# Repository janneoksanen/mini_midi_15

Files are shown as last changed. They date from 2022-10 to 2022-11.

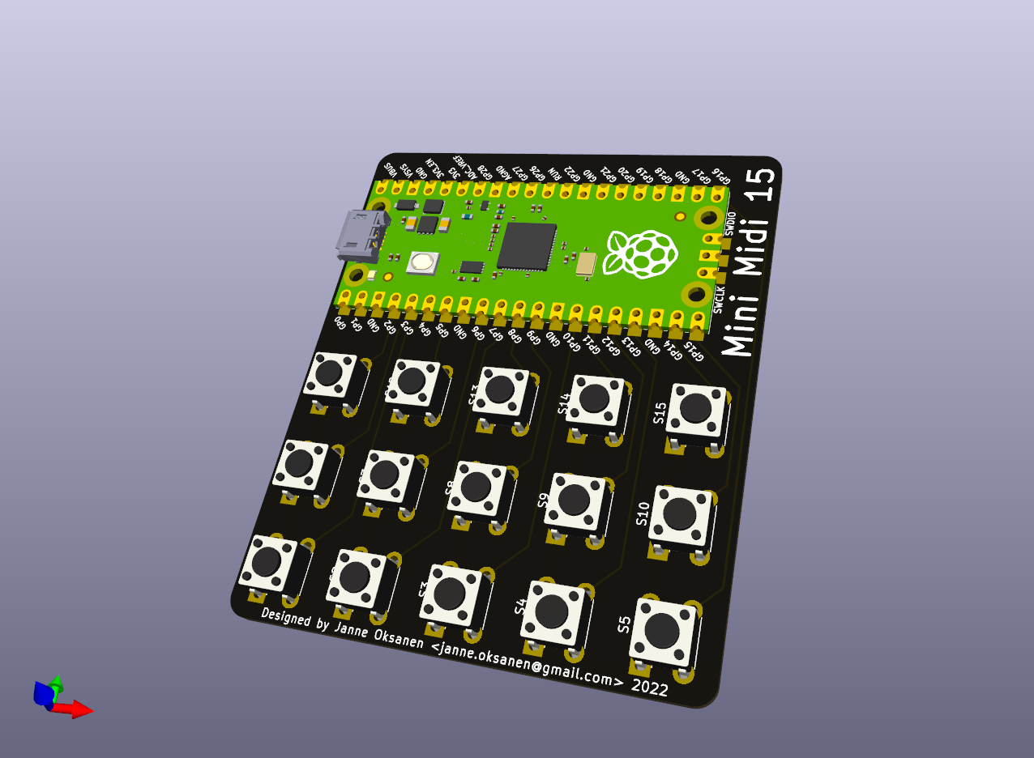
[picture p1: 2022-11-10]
15_button_controller.png

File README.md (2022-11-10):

This is a 15 button USB midi controller based on Raspberry Pi Pico. I created this project because I wanted to be able to control my NeuralDSP guitar amp simulation software. 

The hardware design is based around Raspberry Pi Pico and 6mm tactile switches. The cost to manufacture the PCB should be less than 10 USD for a batch of 5 with shipping included. Raspberry Pi Pico is about 4 USD and the switches liteally cost about a cent each. The total cost of one controller should therefore be about 6 USD and change (micro USB cable not included). 

PCB design was done using KiCad 6
https://www.kicad.org/

The software is based on CircuitPython and uses the Adafruit MIDI library.

Adafruit CircuitPython is released under MIT licence. See the details here:
https://docs.circuitpython.org/en/latest/docs/LICENSE.html?

For installation instructions see the README.txt file inside the firmware directory.

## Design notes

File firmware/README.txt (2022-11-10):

Files included:

adafruit-circuitpython-raspberry_pi_pico-en_US-7.3.3.uf2

	A slightly modified version of Adafruit Circuitpython.
	Only difference is the name of the USB midi device.
	
adafuit_midi

	Adafruid midi library. Added here for convenience so
	that you don't have to download the whole library pack.

Adafuit CircuitPython is published under the MIT licence.
Read licence details here: 
https://docs.circuitpython.org/en/latest/docs/LICENSE.html

code.py

	The actual program that runs the board. By default MIDI
	channel is set to 1. Buttons S1 through S5 send program
	change messages 1 through 5. Buttons 6 through 15 send
	control change messages 1 through 10 with corresponding
	values 1 through 10. If you know any amount of programming
	you should have no problems customizing the code to suit
	your needs.
	
	Check out the MIDI library documentation here:
	https://docs.circuitpython.org/projects/midi/en/latest/api.html#

Installation instructions:

	1. Plug the board into USB
	2. Copy adafruit-circuitpython-raspberry_pi_pico-en_US-7.3.3.uf2
		to the root of the USB drive that appears. The USB drive will
		go away briefly while the Pico installs CircuitPython. It
		will then reappear with a directory called lib in the root
	3. Copy adafuit_midi directory with all its contents inside lib
	4. Replace the code.py file in the root of the USB drive with 
		the code.py provided by me.
	Your MiniMidi 15 is now ready to rock (or pop I don't judge)

Happy hacking, 
Janne Oksanen

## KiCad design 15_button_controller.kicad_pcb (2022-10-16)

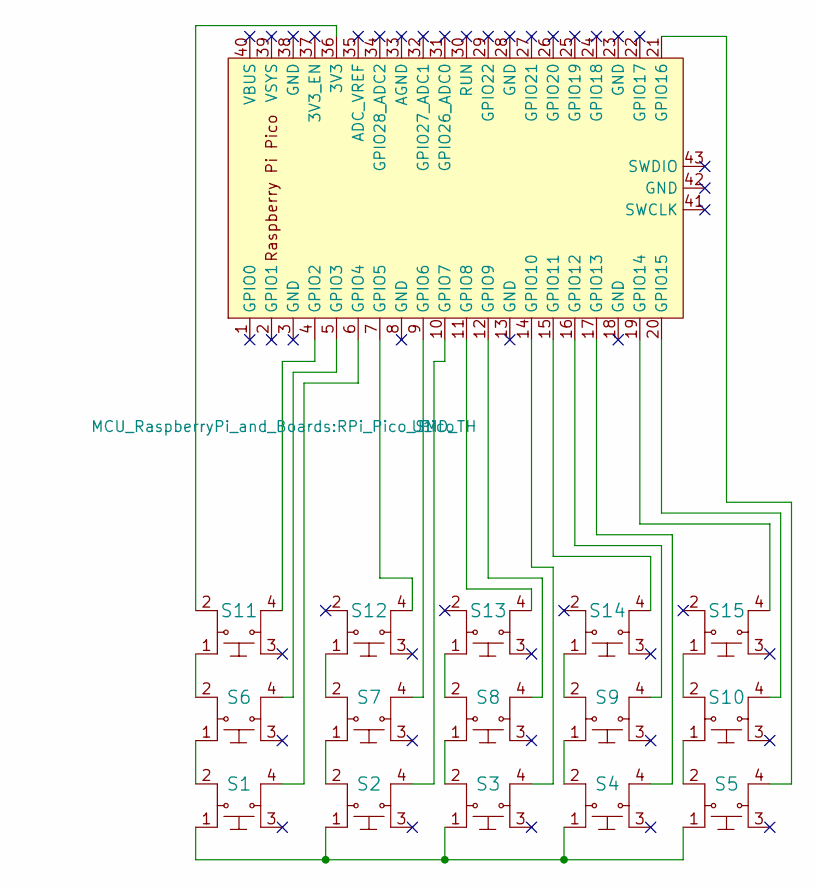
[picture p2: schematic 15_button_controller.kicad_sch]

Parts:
S1, S2, S3, S4, S5, S6, S7, S8, S9, S10, S11, S12, S13, S14, S15: 1825910-6; Switch_Tactile_THT_6x6mm; MPN 1825910-6; Digi-Key_PN 450-1650-ND
U1: Pico; RPi_Pico_SMD_TH

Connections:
unnamed: S1.1, S2.1, S3.1, S4.1, S5.1
unnamed: S1.2, S6.1
unnamed: S1.4, U1.6 (GPIO4)
unnamed: S2.2, S7.1
unnamed: S2.4, U1.10 (GPIO7)
unnamed: S3.2, S8.1
unnamed: S3.4, U1.14 (GPIO10)
unnamed: S4.2, S9.1
unnamed: S4.4, U1.17 (GPIO13)
unnamed: S5.4, U1.21 (GPIO16)
unnamed: S6.4, U1.5 (GPIO3)
unnamed: S7.4, U1.9 (GPIO6)
unnamed: S8.4, U1.12 (GPIO9)
unnamed: S9.4, U1.16 (GPIO12)
unnamed: S5.2, S10.1
unnamed: S10.2, S15.1
unnamed: S10.4, U1.20 (GPIO15)
unnamed: S6.2, S11.1
unnamed: S11.2, U1.36 (3V3)
unnamed: S11.4, U1.4 (GPIO2)
unnamed: S7.2, S12.1
unnamed: S12.4, U1.7 (GPIO5)
unnamed: S8.2, S13.1
unnamed: S13.4, U1.11 (GPIO8)
unnamed: S9.2, S14.1
unnamed: S14.4, U1.15 (GPIO11)
unnamed: S15.4, U1.19 (GPIO14)

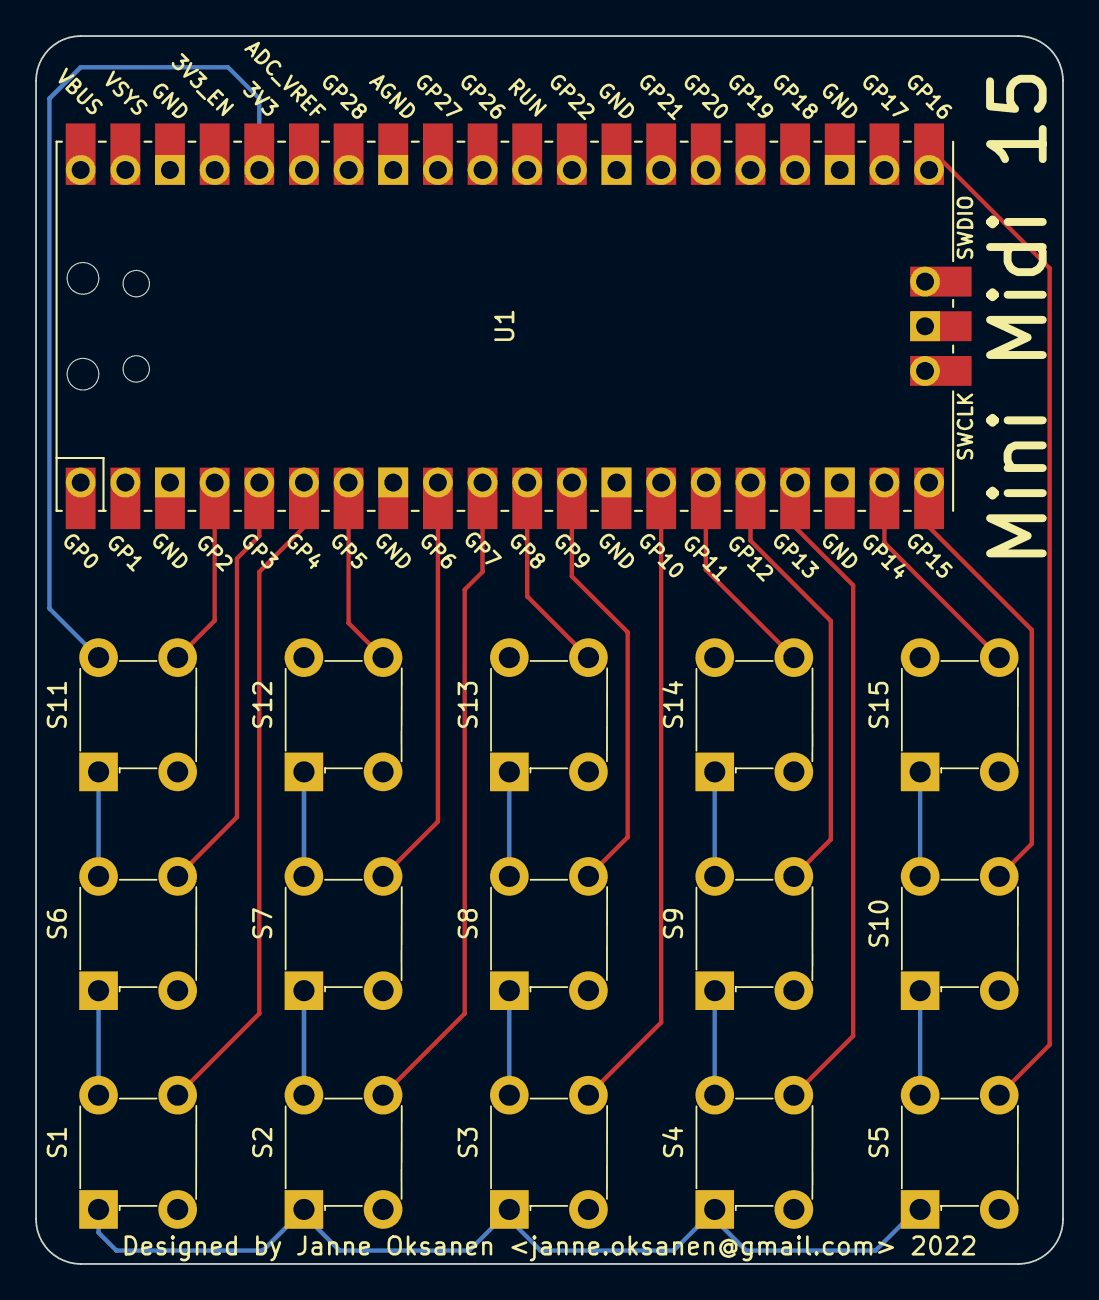
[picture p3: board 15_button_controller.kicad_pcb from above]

Board: 2 copper layers, 58.4 x 69.8 mm, 16 parts (0 on the bottom side), 27 nets.

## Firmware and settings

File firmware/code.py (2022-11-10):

import time
import board
from digitalio import DigitalInOut, Direction, Pull
import usb_midi
import adafruit_midi

led = DigitalInOut(board.LED)
led.direction = Direction.OUTPUT

s1 = DigitalInOut(board.GP4)
s1.direction = Direction.INPUT
s1.pull = Pull.DOWN

s2 = DigitalInOut(board.GP7)
s2.direction = Direction.INPUT
s2.pull = Pull.DOWN

s3 = DigitalInOut(board.GP10)
s3.direction = Direction.INPUT
s3.pull = Pull.DOWN

s4 = DigitalInOut(board.GP13)
s4.direction = Direction.INPUT
s4.pull = Pull.DOWN

s5 = DigitalInOut(board.GP16)
s5.direction = Direction.INPUT
s5.pull = Pull.DOWN

s6 = DigitalInOut(board.GP3)
s6.direction = Direction.INPUT
s6.pull = Pull.DOWN

s7 = DigitalInOut(board.GP6)
s7.direction = Direction.INPUT
s7.pull = Pull.DOWN

s8 = DigitalInOut(board.GP9)
s8.direction = Direction.INPUT
s8.pull = Pull.DOWN

s9 = DigitalInOut(board.GP12)
s9.direction = Direction.INPUT
s9.pull = Pull.DOWN

s10 = DigitalInOut(board.GP15)
s10.direction = Direction.INPUT
s10.pull = Pull.DOWN

s11 = DigitalInOut(board.GP2)
s11.direction = Direction.INPUT
s11.pull = Pull.DOWN

s12 = DigitalInOut(board.GP5)
s12.direction = Direction.INPUT
s12.pull = Pull.DOWN

s13 = DigitalInOut(board.GP8)
s13.direction = Direction.INPUT
s13.pull = Pull.DOWN

s14 = DigitalInOut(board.GP11)
s14.direction = Direction.INPUT
s14.pull = Pull.DOWN

s15 = DigitalInOut(board.GP14)
s15.direction = Direction.INPUT
s15.pull = Pull.DOWN


USB_MIDI_channel = 1  # pick your USB MIDI out channel here, 1-16
usb_midi = adafruit_midi.MIDI(midi_out=usb_midi.ports[1], out_channel=USB_MIDI_channel - 1)
from adafruit_midi.program_change import ProgramChange
from adafruit_midi.control_change import ControlChange

debounce_delay = 0.3 # seconds

# set the led on by default
led.value = True

while True:
    if s1.value:
        led.value = False
        usb_midi.send(ProgramChange(1))
        time.sleep(debounce_delay)
        led.value = True
    if s2.value:
        led.value = False
        usb_midi.send(ProgramChange(2))
        time.sleep(debounce_delay)
        led.value = True
    if s3.value:
        led.value = False
        usb_midi.send(ProgramChange(3))
        time.sleep(debounce_delay)
        led.value = True
    if s4.value:
        led.value = False
        usb_midi.send(ProgramChange(4))
        time.sleep(debounce_delay)
        led.value = True
    if s5.value:
        led.value = False
        usb_midi.send(ProgramChange(5))
        time.sleep(debounce_delay)
        led.value = True
    if s6.value:
        led.value = False
        usb_midi.send(ControlChange(1,1))
        time.sleep(debounce_delay)
        led.value = True
    if s7.value:
        led.value = False
        usb_midi.send(ControlChange(2,2))
        time.sleep(debounce_delay)
        led.value = True
    if s8.value:
        led.value = False
        usb_midi.send(ControlChange(3,3))
        time.sleep(debounce_delay)
        led.value = True
    if s9.value:
        led.value = False
        usb_midi.send(ControlChange(4,4))
        time.sleep(debounce_delay)
        led.value = True
    if s10.value:
        led.value = False
        usb_midi.send(ControlChange(5,5))
        time.sleep(debounce_delay)
        led.value = True
    if s11.value:
        led.value = False
        usb_midi.send(ControlChange(6,6))
        time.sleep(debounce_delay)
        led.value = True
    if s12.value:
        led.value = False
        usb_midi.send(ControlChange(7,7))
        time.sleep(debounce_delay)
        led.value = True
    if s13.value:
        led.value = False
        usb_midi.send(ControlChange(8,8))
        time.sleep(debounce_delay)
        led.value = True
    if s14.value:
        led.value = False
        usb_midi.send(ControlChange(9,9))
        time.sleep(debounce_delay)
        led.value = True
    if s15.value:
        led.value = False
        usb_midi.send(ControlChange(10,10))
        time.sleep(debounce_delay)
        led.value = True

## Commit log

2022-10-16 Final design v1
    [15_button_controller-B_Cu.gbr, 15_button_controller-B_Mask.gbr, 15_button_controller-B_Silkscreen.gbr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]
2022-10-18 Added gerber files
    [15_button_controller-B_Cu.gbl, 15_button_controller-B_Mask.gbs, 15_button_controller-B_Silkscreen.gbo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]
2022-11-10 Added a 3D rendering of the PCB
